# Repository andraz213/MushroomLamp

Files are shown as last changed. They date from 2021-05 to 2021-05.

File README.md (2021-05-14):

# MushroomLamp
 
A birthday present for my girlfriend. 

It's a bedside lamp. It features RGB ws2812 led lights and possible IoT expansion because of the esp8266 that is used. 

The lamp turns on when the smallest mushroom is pressed. The light is dimmed when the lamp turns on because it's meant to be a bedside lamp that can be used in the middle of the night. The brightness can be adjusted by rotating the smallest mushroom. Pressing on the smallest mushroom cycles the different modes of operation:

1. Static warm light
2. Slow pastel changing colors
3. Shooting stars shower
4. Fire animation 

The lamp is turned off by turning the brightness down.

## Enclosure

Mushrooms and the base were modeled in Fusion 360. The model is available on: https://a360.co/3hpJmct

All parts were printed on a Creality ender3V2 with 0.25mm layer height and 33% gyroid infill at 205C out of ecoPLA white filament. Then it was sanded down with 220 grit sandpaper and glued with Loctite glue.

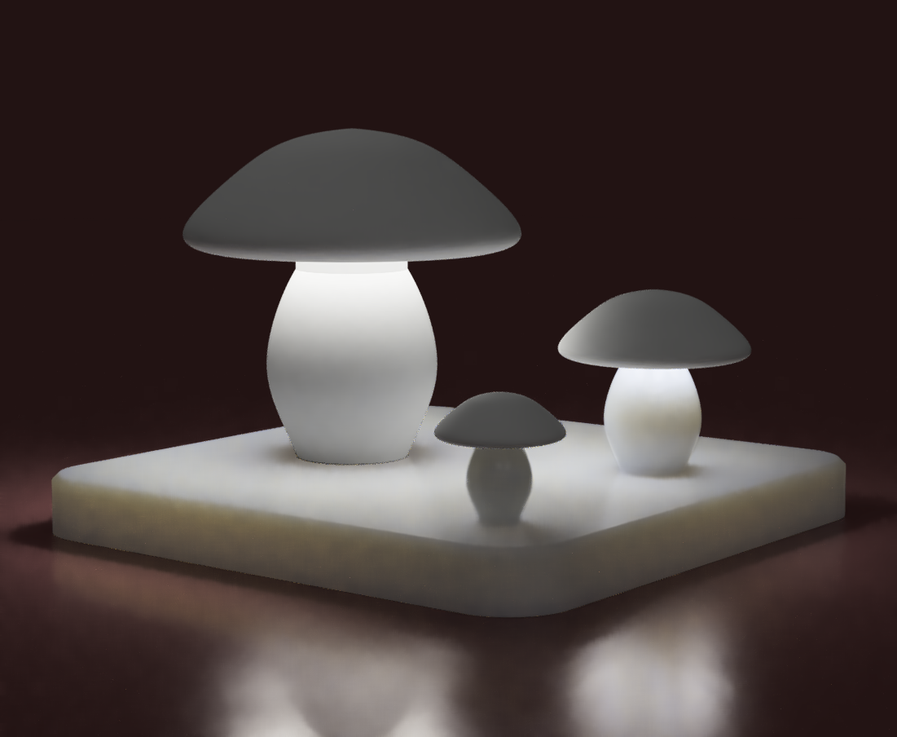
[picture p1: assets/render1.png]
Render


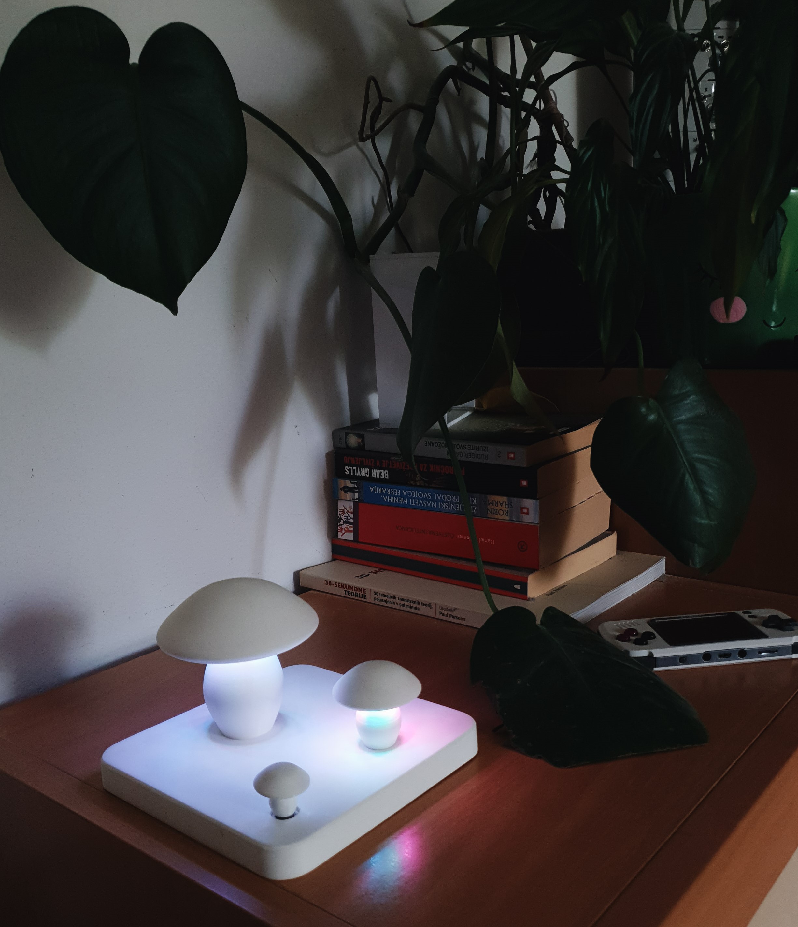
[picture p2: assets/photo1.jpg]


## Electronics

The stars of the show are two Neopixel rings. The bigger one features 12 chips, the smaller one has 8 chips. They're controlled by a WEMOS D1 board with an esp8266 MCU. I used a rotary encoder for user input and a 18650 Li-ion battery with a TP4056 battery protection circuit.

I have implemented a few power-saving features. The MCU is never turned off and is only put to sleep. Neopixels also use each 1mA even when they're not used, so I used an IRFZ44N MOSFET to cut the power to them when the unit is off. Additionally, I have disabled all wifi functionally to further reduce consumption.

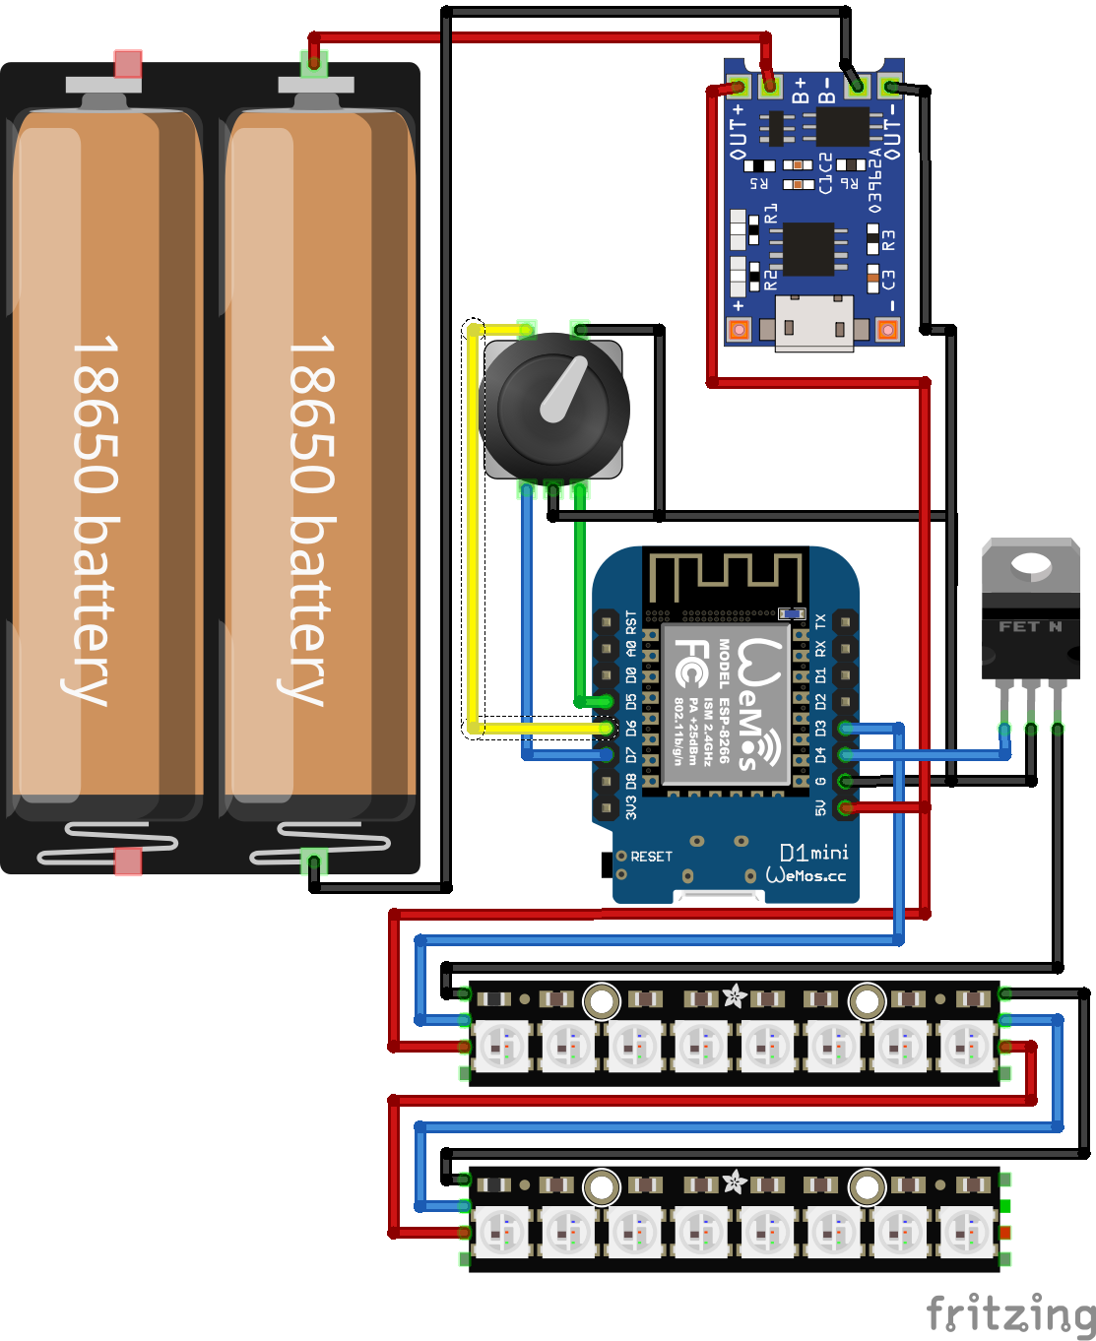
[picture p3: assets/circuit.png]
Circuit


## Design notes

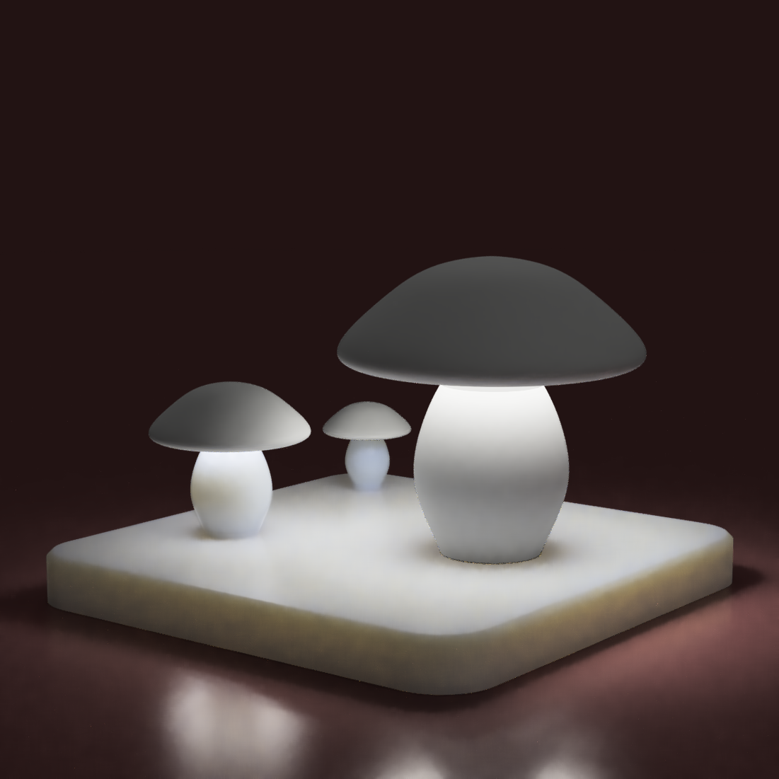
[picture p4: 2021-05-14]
assets/render2.png

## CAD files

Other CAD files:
3d_model/MushroomLamp v36.f3d

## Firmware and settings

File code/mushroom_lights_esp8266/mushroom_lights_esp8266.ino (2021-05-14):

#include "handle_input.h"
#include <ESP8266WiFi.h>
#include "handle_sleep.h"
#include "handle_led.h"
#include "handle_ota.h"


void setup() {
  WiFi.mode(WIFI_OFF);
  wifi_fpm_set_sleep_type (LIGHT_SLEEP_T);
  WiFi.forceSleepBegin();   // if you dont need wifi, ~22ma instead of ~75ma

  Serial.begin(115200);

  Serial.println("hejj");

  setup_pins();

  Serial.println("hejjd");




}
long prevl = millis();
void loop() {
  // put your main code here, to run repeatedly:
  //Serial.println("hejjf");

  if(is_ota()){
    //handle_ota();
  }

  int del = millis() - prevl;
  prevl = millis();
  //Serial.print("FPS: ");
  //Serial.println(1000 / del);

  handle_leds();
  handle_sleep();

  yield();
  delay(16);

    //Serial.println("Exit light sleep mode");
}

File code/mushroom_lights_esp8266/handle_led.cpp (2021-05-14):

#include "handle_led.h"
#include <Adafruit_NeoPixel.h>
#include <Arduino.h>
#include "handle_input.h"


#define NUMPIXELS 20

int to_show [NUMPIXELS][3];
bool inited_neo = false;
float pixs[NUMPIXELS][2][3];
Adafruit_NeoPixel pixels(NUMPIXELS, LED_PIN, NEO_GRB + NEO_KHZ800);

void reset_leds(){
  inited_neo = false;
}

void show_leds(){
  if(init_neo()){
    pixels.clear();


    for(int i = 0; i < NUMPIXELS; i++){
      pixels.setPixelColor(i, pixels.Color(to_show[i][0], to_show[i][1], to_show[i][2]));

    }

    pixels.show();
  }
}


bool init_neo(){
  if(!inited_neo){
      pixels.begin();
      pixels.setBrightness(255);
      for(int i = 0; i < NUMPIXELS; i++){
        to_show[i][0] = 0;
        to_show[i][1] = 0;
        to_show[i][2] = 0;
        pixels.setPixelColor(i, pixels.Color(to_show[i][0], to_show[i][1], to_show[i][2]));

      }

      pixels.show();

      for(int i = 0; i<NUMPIXELS; i++){
        pixs[i][0][0] = 0;
        pixs[i][0][1] = 0;
        pixs[i][0][2] = 0;
        pixs[i][1][0] = 0;
        pixs[i][1][1] = 0;
        pixs[i][1][2] = 0;
      }

      inited_neo = true;
  }

digitalWrite(MOSFET_PIN, HIGH);
return inited_neo;

}


void handle_leds(){
  int mode = get_mode(); // get mode

  int brightness = 100;


  switch(mode){
    case 0 : warm_white(); break;
    case 1 : efekt_rgb(); break;
    case 2 : calculate_stars(); break;
    case 3: calculate_fire(); break;
  }


  // Serial.println("HUH");

  recalc_brightness();
  // Serial.println("HHHH");
  show_leds();
  // Serial.println("HHHHsadfaf");


}



void recalc_brightness(){
  int brightness = get_brightness();
  int fak = 0;
  if(brightness < 15){
    fak = brightness;
  } else {
  fak = map(brightness * brightness, 15*15, 100*100, 15, 100);
  }


  for(int i = 0; i < NUMPIXELS; i++){
    to_show[i][0] = to_show[i][0] * fak / 100;
    to_show[i][1] = to_show[i][1] * fak / 100;
    to_show[i][2] = to_show[i][2] * fak / 100;

    if(to_show[i][0] < 0){
      to_show[i][0] = 0;
    }
    if(to_show[i][1] < 0){
      to_show[i][1] = 0;
    }
    if(to_show[i][2] < 0){
      to_show[i][2] = 0;
    }
    if(to_show[i][0] > 255){
      to_show[i][0] = 255;
    }
    if(to_show[i][1] > 255){
      to_show[i][1] = 255;
    }
    if(to_show[i][2] > 255){
      to_show[i][2] = 255;
    }
  }

}





void efekt_rgb(){


  for(int i = 0; i<NUMPIXELS; i++){
    float d = abs(pixs[i][0][0] - pixs[i][1][0]);
    d += abs(pixs[i][0][1] - pixs[i][1][1]);
    d += abs(pixs[i][0][2] - pixs[i][1][2]);


    if(abs(d) < 4.0){
      int r = random(25);
      int g = random(25);
      int b = random(25);

      int avg = (r + g + b)/3;
      int delta = abs(avg - r) + abs(avg - g) + abs(avg - b);
      while(delta < 30 || avg > 20){

        r = random(25);
        g = random(25);
        b = random(25);

        avg = (r + g + b)/3;
        delta = abs(avg - r) + abs(avg - r) + abs(avg - r);
      }

      pixs[i][1][0] = r;
      pixs[i][1][1] = map(g, 0, 25, 0, 20);
      pixs[i][1][2] = map(b, 0, 25, 0, 22);

    }

    float fak = (float)(random(10) + 10)/1000.0;
    if(fak < 0.01){
      fak = 0.01;
    }

    pixs[i][0][0] += fak * (pixs[i][1][0] - pixs[i][0][0]);
    pixs[i][0][1] += fak * (pixs[i][1][1] - pixs[i][0][1]);
    pixs[i][0][2] += fak * (pixs[i][1][2] - pixs[i][0][2]);

    to_show[i][0] = (int)pixs[i][0][0] * 10.0;
    to_show[i][1] = (int)pixs[i][0][1] * 10.0;
    to_show[i][2] = (int)pixs[i][0][2] * 10.0;

  }

}






const int num_stars = 4;
// kje, kok bliz(močno), kok hitr, kera faza
star_data stars[num_stars];

long prev_stars = 0;

bool first_stars = true;

void calculate_stars(){
 Serial.println("stars");

  for(int i = 0; i<NUMPIXELS; i++){
    to_show[i][0] = 0;
    to_show[i][1] = 0;
    to_show[i][2] = 0;
  }

  int calc_num = num_stars; // * stars_data[0] / 100;

  if(first_stars){
    calc_num = num_stars;
  }

// Serial.println("hejadsfjg");
  for(int i = 0; i<calc_num; i++){
    if(stars[i].done == true || first_stars){
      stars[i].done = false;
      stars[i].position = random(NUMPIXELS);
      stars[i].distance = 400.0;
      stars[i].initial_distance = stars[i].distance;
      stars[i].speed = random(70) + 10;
      stars[i].strength = random(255);
    }

// Serial.println("hejjgaaa");
      for(int j = 0; j<3; j++){

        int rp = j*10;

        float dist_to_star = abs(stars[i].distance)*abs(stars[i].distance);


        float brightness = stars[i].strength - (stars[i].strength * dist_to_star / pow(stars[i].initial_distance, 2)); //  map(dist_to_star, 0, 130, stars[i].strength, 0);// / dist_to_star;
        brightness /= ((j*2)+1);
        // Serial.println("hejjgbbb");
        if(j == 0){
          to_show[stars[i].position][0] += (int)brightness;
          to_show[stars[i].position][1] += (int)brightness;
          to_show[stars[i].position][2] += (int)brightness;
        } else {

          int pos = stars[i].position + j;
          pos %= NUMPIXELS;

          to_show[pos][0] += (int)brightness;
          to_show[pos][1] += (int)brightness;
          to_show[pos][2] += (int)brightness;

          pos = stars[i].position - j + NUMPIXELS;
          pos %= NUMPIXELS;

          to_show[pos][0] += (int)brightness;
          to_show[pos][1] += (int)brightness;
          to_show[pos][2] += (int)brightness;

        }
        // Serial.println("hejjgccc");

        stars[i].distance -= stars[i].speed * (millis() - prev_stars) / 400.0;

        if(stars[i].distance < -400){
          stars[i].done = true;
        }
  }


    }
    // Serial.println("hejjgddd");
    prev_stars = millis();
        first_stars = false;

        // Serial.println("hejjgsss");
        for(int i = 0; i<NUMPIXELS; i++){
          int val = to_show[i][0];
          if(val> 255){
            val = 255.0;
          }

          // Serial.println("hejjgsdfs");
          int calc = map(val*val, 0, 255*255, 0, 255);
            to_show[i][0] = (int)calc;
            to_show[i][1] = (int)((float)calc * 0.6);
            to_show[i][2] = (int)((float)calc * 0.3);

            // Serial.println(i);
          }
          // Serial.println("hsdf");

}



void warm_white(){
  int brightness = get_brightness();

  int r = 255;
  int g = 119;
  int b = 49;

  if(brightness < 50){
    g = map(brightness, 0, 50, 90, 119);
    b = map(brightness, 0, 50, 30, 49);

  }
  Serial.println("r");
  Serial.println(r);
  Serial.println("g");
  Serial.println(g);
  Serial.println("b");
  Serial.println(b);



  for(int i = 0; i < NUMPIXELS; i++){


    to_show[i][0] = r;
    to_show[i][1] = g;
    to_show[i][2] = b;
  }

}








int prev [NUMPIXELS][3];
int current [NUMPIXELS][3];
int next[NUMPIXELS][3];
long prevupd = 0;
int update_interval = 150;
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
